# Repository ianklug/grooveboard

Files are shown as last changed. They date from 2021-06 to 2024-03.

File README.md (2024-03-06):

# Grooveboard
A four-key mechanical keyboard for rhythm games.

Grooveboard PCB

Design by [ianklug](https://ianklug.com). Art by [clue](https://clue.graphics).

Special thanks to [Sebastiaan Swinkels](https://github.com/C44Supra) for technical assistance.

Made with [KiCad](https://www.kicad.org/).

*Please clone this repository using the `--recurse-submodules` flag. Some of the required symbol and footprint libraries will not be included otherwise.*

## Versions

*Please note that the RP2040 models are functional at a hardware level, but software is incomplete.*

The 2.x versions (grooveboard-rp) use the RP2040 MCU, and require different firmware from the 1.x versions. They also include a few new features and refinements over the 1.x models, including M2 mounting holes and improved key spacing.

The 1.x versions (grooveboard-atmel) use the Atmega32U4 MCU, in either the MU or AU footprint. These versions are no longer recommended.

There are three types of Grooveboard, each supporting different types of switches.

**Grooveboard:** Compatible with MX, Choc, or Alps-style switches. Switches must be soldered.

**Grooveboard MX:** Compatible with MX-style switches only. Uses Kailh MX hot-swap sockets.

**Grooveboard Choc:** Compatible with Choc-style switches only. Uses Kailh Choc hot-swap sockets.

## Firmware

Grooveboard is powered by [QMK Firmware](https://qmk.fm).

Grooveboard ships by default with firmware supporting [VIA Configurator](https://caniusevia.com). To modify your keymap, install VIA Configurator, plug in your Grooveboard, and begin customizing. Changes will be applied immediately.

For more advanced functionality, you may also customize Grooveboard using [QMK Configurator](https://config.qmk.fm), or by using QMK on the command line. This will require a reflash of your board's firmware. Use [QMK Toolbox](https://github.com/qmk/qmk_toolbox) to flash if on Windows or MacOS, or the QMK CLI with avrdude on Linux.

## Manufacturing

**Manufacture at your own risk. I can not guarantee the quality or functionality of boards not sold directly by me.**

**Please note that most PCB manufacturers have a minimum order quantity of five units.**

Hand-soldering Grooveboards from scratch is extremely difficult and NOT recommended due to the small size of the surface-mount components and their pads. Instead, PCB assembly services can source and assemble all the small parts on the bottom of the board. Depending on the manufacturer, you may only need to hand-solder some of the larger parts, such as the USB port and the switches/sockets.

I can personally recommend [JLCPCB](https://jlcpcb.com) or [PCBWay](https://pcbway.com/), but most PCB manufacturers should be capable of producing Grooveboard.

Zipped gerber files are present for the production designs of each variation of Grooveboard. They are called `<variation>-gerbers-<version>.zip` and should be compatible with most PCB manufacturing services.

If you will be ordering from JLCPCB, use `<variation>-gerbers-jlcpcb-<version>.zip`. These gerbers have the JLCPCB serial number placed in an easily-readable location on the back of the board. Make sure to choose "Specify a location" under "Remove Order Number" so that this number is printed where expected.

Production Grooveboards are two-layer FR4, 1.6mm thick. The RP2040 versions measure 120x25mm. They are assembled using lead-free solder. BOM and Centroid files are present for each board in the format expected by JLCPCB.

The USB connector is a [GCT USB4085](https://gct.co/connector/usb4085). The hot-swap sockets are [Kailh sockets](https://www.kailhswitch.com/mechanical-keyboard-switches/box-switches/mechanical-keyboard-switches-kailh-pcb-socket.html). **Sockets are different for MX switches and Choc switches! Make sure to use the right kind for the model you have chosen.**

## License

Shield: [][cc-by-sa]

This work is licensed under a
[Creative Commons Attribution-ShareAlike 4.0 International License][cc-by-sa].

[][cc-by-sa]

[cc-by-sa]: http://creativecommons.org/licenses/by-sa/4.0/
[cc-by-sa-image]: https://licensebuttons.net/l/by-sa/4.0/88x31.png
[cc-by-sa-shield]: https://img.shields.io/badge/License-CC%20BY--SA%204.0-lightgrey.svg

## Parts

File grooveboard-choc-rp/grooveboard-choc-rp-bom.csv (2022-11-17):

Comment | Designator | Footprint | LCSC Part Number
10uF | C1, C2 | 402 | C15525
100nF | C3, C8, C9, C10, C11, C12, C13, C14, C15, C16 | 402 | C1525
1uF | C4, C5 | 402 | C52923
10pF | C6, C7 | 402 | C32949
Schottky | D1 | SOD-323 | C191023
500mA | F1 | 805 | C261942
10k | R7 | 402 | C25744
5.1k | R2, R3 | 402 | C25905
22 | R4, R5 | 402 | C25092
1k | R6, R8 | 402 | C25905
TS-1187A-B-A-B | SW1, SW2 | SMD | C318884
RP2040 | U1 | QFN-56(7x7) | C2040
W25Q128JV | U2 | WSON-8_5x6mm | C190862
3.3V | U3 | SOT-25 | C51118
12MHz | Y1 | SMD3225-4P | C255903

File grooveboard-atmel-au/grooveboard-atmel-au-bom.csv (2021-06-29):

Comment | Designator | Footprint | LCSC Part Number
4.7nF | C1 | 402 | C1538
1uF | C2 | 402 | C52923
100nF | C3, C4, C5 | 402 | C1525
10uF | C6 | 402 | C15525
22pF | C7, C8 | 402 | C1555
1M | R1 | 402 | C26083
5.1k | R2, R3 | 402 | C25905
22 | R4, R5 | 402 | C25092
10k | R6, R7 | 402 | C25744
500mA | F1 | 805 | C261942
ATmega32U4-AU | U1 | TQFP-44_10.0x10.0x0.8P | C44854
16MHz | X1 | SMD-3225_4P | C13738
TS-1187A-B-A-B | SW1 | SMD-SW-4_5.1x5.1x1.5 | C318884

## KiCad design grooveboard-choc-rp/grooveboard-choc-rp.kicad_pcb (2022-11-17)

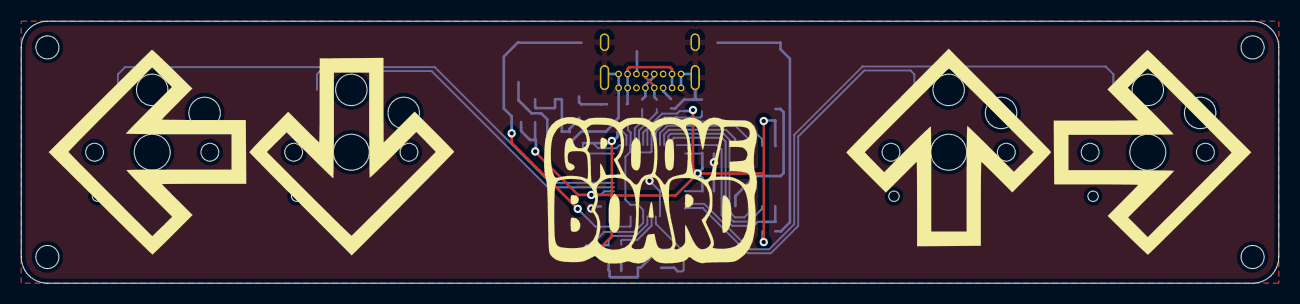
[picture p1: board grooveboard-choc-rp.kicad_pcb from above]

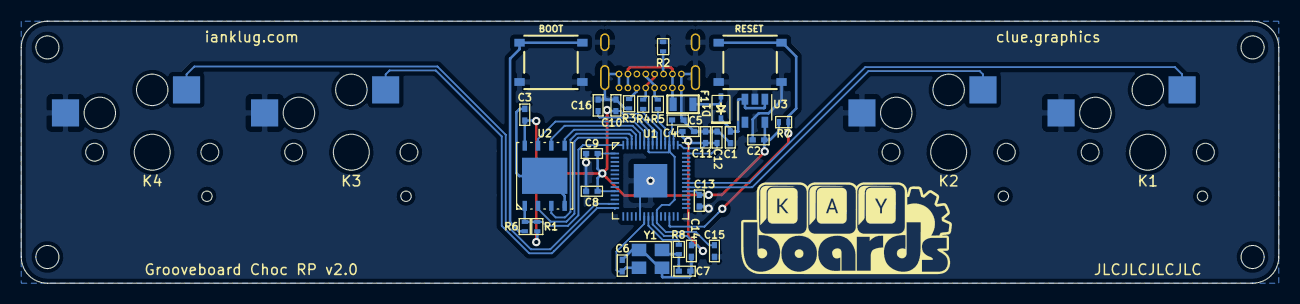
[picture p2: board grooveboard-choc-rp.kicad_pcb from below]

Board: 2 copper layers, 120.0 x 25.0 mm, 41 parts (32 on the bottom side), 27 nets.

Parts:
C1, C2: 10uF; C_0402
C3, C8, C9, C10, C11, C12, C13, C14, C15, C16: 100nF; C_0402
C4, C5: 1uF; C_0402
C6, C7: 10pF; C_0402
D1: 20V 1A; D_SOD-323
F1: 500mA; Fuse_0805
H1, H2, H3, H4: MountingHole; MountingHole_2.2mm_M2
J1: USB_C_Receptacle_USB2.0; USB_C_GCT_USB4085
K1, K2, K3, K4: MX-NoLED; Kailh_socket_PG1350
R1: DNP; R_0402
R2, R3: 5.1k; R_0402
R4, R5: 27; R_0402
R6, R8: 1k; R_0402
R7: 10k; R_0402
SW1: BOOT; TS-1187A-B-A-B
SW2: RESET; TS-1187A-B-A-B
U1: RP2040
U2: W25Q128JV; W25Q128JVPIQ
U3: AP2112K-3.3; SOT-23-5
Y1: 12MHz; Crystal_SMD_3225-4pin_3.2x2.5mm

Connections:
+5V: C1.1, D1.1, U3.1, U3.3
D+: J1.A6, J1.B6, R4.1
D-: J1.A7, J1.B7, R5.1
GND: C1.2, C2.2, C3.2, C4.2, C5.2, C6.2, C7.2, C8.2, C9.2, C10.2, C11.2, C12.2, C13.2, C14.2, C15.2, C16.2, J1.A1, J1.A12, J1.B1, J1.B12, J1.S1, K1.2, K2.2, K3.2, K4.2, R2.1, R3.1, SW1.1, SW2.2, U1.19, U1.57, U2.4, U3.2, Y1.2, Y1.4
K1: K1.1, U1.35
K2: K2.1, U1.34
K3: K3.1, U1.14
K4: K4.1, U1.13
unnamed: C7.1, R8.2, Y1.1
unnamed: D1.2, F1.1
unnamed: F1.2, J1.A4, J1.A9, J1.B4, J1.B9
unnamed: J1.A5, R3.2
unnamed: J1.B5, R2.2
unnamed: R4.2, U1.47
unnamed: R5.2, U1.46
unnamed: R6.1, SW1.2
unnamed: R7.1, SW2.1, U1.26
QSPI_0: U1.53, U2.5
QSPI_1: U1.55, U2.2
QSPI_2: U1.54, U2.3
QSPI_3: U1.51, U2.7
QSPI_SCLK: U1.52, U2.6
QSPI_SS: R1.2, R6.2, U1.56, U2.1
VREG_VIN: C2.1, C3.1, C4.1, C8.1, C9.1, C10.1, C11.1, C12.1, C13.1, C14.1, R1.1, R7.2, U1.1, U1.10, U1.22, U1.33, U1.42, U1.43, U1.44, U1.48, U1.49, U2.8, U3.5
VREG_VOUT: C5.1, C15.1, C16.1, U1.23, U1.45, U1.50
XIN: C6.1, U1.20, Y1.3
XOUT: R8.1, U1.21

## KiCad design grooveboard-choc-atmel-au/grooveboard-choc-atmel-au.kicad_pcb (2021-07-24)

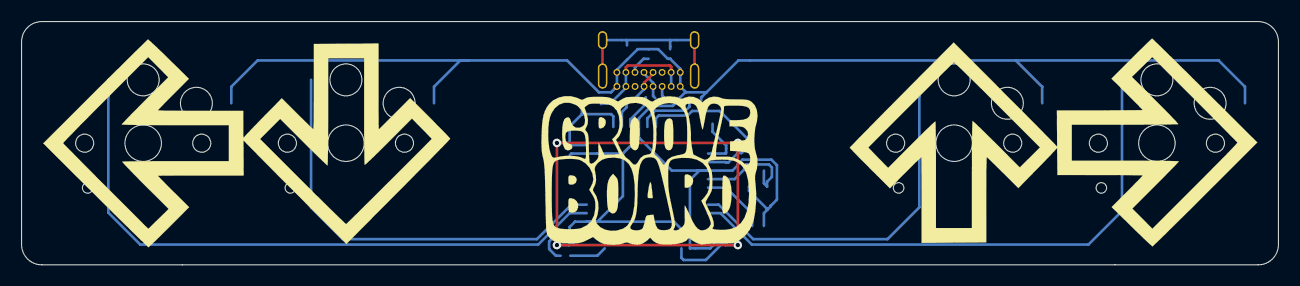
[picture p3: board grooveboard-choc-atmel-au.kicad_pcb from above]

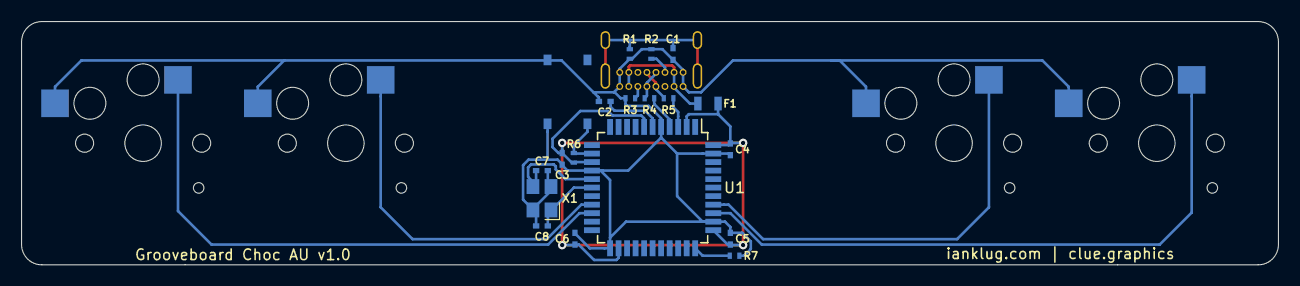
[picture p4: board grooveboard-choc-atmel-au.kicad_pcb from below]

Board: 2 copper layers, 118.1 x 22.9 mm, 24 parts (19 on the bottom side), 19 nets.

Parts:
C1: 4.7nF; C_0402
C2: 1uF; C_0402
C3, C4, C5: 0.1uF; C_0402
C6: 10uF; C_0402
C7, C8: 22pF; C_0402
F1: 500mA; Fuse_0805
J1: USB_C_Receptacle_USB2.0; USB_C_GCT_USB4085
MX1, MX2, MX3, MX4: MX-NoLED; Kailh_socket_PG1350
R1: 1M; R_0402
R2, R3: 5.1k; R_0402
R4, R5: 22; R_0402
R6, R7: 10k; R_0402
SW1: SW_Push; TS-1187A-B-A-B
U1: ATmega32U4-AU; TQFP-44_10x10mm_P0.8mm
X1: 16MHz; Crystal_SMD_3225-4pin_3.2x2.5mm

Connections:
D+: R4.1, U1.4
D-: R5.1, U1.3
GND: C1.2, C2.2, C3.2, C4.2, C5.2, C6.2, C7.1, C8.1, J1.A1, J1.A12, J1.B1, J1.B12, MX1.2, MX2.2, MX3.2, MX4.2, R1.2, R2.1, R3.1, R7.1, SW1.1, U1.5, U1.15, U1.23, U1.35, U1.43, X1.2, X1.4
MX1: MX1.1, U1.36
MX2: MX2.1, U1.37
MX3: MX3.1, U1.19
MX4: MX4.1, U1.20
unnamed: C1.1, J1.S1, R1.1
unnamed: C2.1, U1.6
unnamed: C7.2, U1.16, X1.3
unnamed: C8.2, U1.17, X1.1
unnamed: F1.2, J1.A4, J1.A9, J1.B4, J1.B9
unnamed: J1.A5, R3.2
unnamed: J1.A6, J1.B6, R4.2
unnamed: J1.A7, J1.B7, R5.2
unnamed: J1.B5, R2.2
unnamed: R7.2, U1.33
RST: R6.2, SW1.2, U1.13
VCC: C3.1, C4.1, C5.1, C6.1, F1.1, R6.1, U1.2, U1.7, U1.14, U1.24, U1.34, U1.44

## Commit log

2021-06-29 add AU versions of hot swap boards
    [grooveboard-choc-au-bom.csv, grooveboard-choc-au.kicad_pcb, grooveboard-choc-au.sch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]
2021-06-30 update board designs to unify key wiring and firmware
    [grooveboard-au-bom.csv, grooveboard-au.kicad_pcb, grooveboard-au.sch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]
2021-07-24 update silkscreen issue
    [grooveboard-choc-au.kicad_pcb, grooveboard-mx-au.kicad_pcb]
2022-11-05 rp2040 initial commit
    [grooveboard-atmel-au-bom.csv, grooveboard-atmel-au.kicad_pcb, grooveboard-atmel-au.sch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]
2022-11-17 fix incorrect resistor part number in BOM
    [grooveboard-choc-rp-bom.csv, grooveboard-mx-rp-bom.csv, grooveboard-rp-bom.csv]
2022-11-17 update usb resistors
    [grooveboard-choc-rp-bom.csv, grooveboard-choc-rp.kicad_pcb, grooveboard-choc-rp.sch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]

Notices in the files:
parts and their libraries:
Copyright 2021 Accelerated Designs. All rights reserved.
